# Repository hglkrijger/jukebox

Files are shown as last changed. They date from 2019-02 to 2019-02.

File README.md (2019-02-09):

# Arduino NFC Jukebox

Recently, my wife and I had the idea of printing a song card for our 16 month old daughter. What this means is there are pictures printed on some cardstock which she can point to, and one of us sings the songs represented by that picture. 

After a few days of continuous singing, I decided to build a jukebox for her instead. I wanted to enable simple song selection using NFC cards with feedback from an LED. I also wanted to introduce her to the concept of sequences, while allowing her some simple level of control using a button. Finally, I would also need a way to change volume and other control functions.

This is a quick walkthrough for anyone who might like to do the same.

## Components

| Part | Link | Cost |
| ---|---|---|
| NTAG 215 NFC cards | [Amazon](https://www.amazon.com/gp/product/B075CL71FK/ref=ppx_yo_dt_b_asin_title_o01__o00_s00?ie=UTF8&psc=1) | ~60c ea |
| NTAG 213 NFC tags | [Amazon](https://www.amazon.com/gp/product/B07K6H6K43/ref=ppx_yo_dt_b_asin_title_o05__o00_s03?ie=UTF8&psc=1) | ~40c ea |
| DFPlayer mini | [Amazon](https://www.amazon.com/gp/product/B01MQD5IIA/ref=ppx_yo_dt_b_asin_title_o03__o00_s00?ie=UTF8&psc=1) | ~$4 |
| Power supply | [Amazon](https://www.amazon.com/gp/product/B06Y1LF8T5/ref=ppx_yo_dt_b_asin_title_o03__o00_s00?ie=UTF8&psc=1) | ~$9 |
| Illuminated latching switch | [Adafruit](https://www.adafruit.com/product/1442) | ~$2 |
| 3W speakers | [Amazon](https://www.amazon.com/gp/product/B0738NLFTG/ref=ppx_yo_dt_b_asin_title_o08__o00_s02?ie=UTF8&psc=1) | ~$8 |
| PN532 NFC shield | [Adafruit](https://www.adafruit.com/product/789) | ~$40 |
| Arduino Uno R3 | [Amazon](https://www.amazon.com/Elegoo-EL-CB-001-ATmega328P-ATMEGA16U2-Arduino/dp/B01EWOE0UU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) | ~$12 |
| Sandisk microSDHC card | [Amazon](https://smile.amazon.com/gp/product/B073JWXGNT/ref=oh_aui_search_asin_title?ie=UTF8&psc=1) | ~8 |

You will also need:

- Assorted brass standoffs
- Solid core wire
- Electrical insulation tape
- 8x M2 3mm screws (for speaker mounts)
- 4x M2 3mm screws (for Arduino mounts)
- 3x M2.5 3mm screws (for enclosure)
- 3x 2.5mm hex nuts (for enclosure)
- Soldering iron and solder
- MP3 songs

Total cost: ~$100

## Case

I designed the outer case and trim using Tinkercad, and printed in two colors. You can find all those parts here:

- [Back case](case/01%20-%20grey%20-%20back.stl)
- [Front case](case/02%20-%20grey%20-%20front.stl)
- [Trim, grey](case/03%20-%20grey%20-%20decoration.stl)
- [Trim, red](case/04%20-%20red%20-%20decoration.stl)

## Control tags

I found these handy key fobs on Thingiverse, which I used to represent control tags:

- [volume Up](https://www.thingiverse.com/thing:2852132)
- [volume Down](https://www.thingiverse.com/thing:2852051)
- [Stop](https://www.thingiverse.com/thing:2852109)

Scaling to 50% was a good size for these prints. The NFC stickers were attached to these, for use as controls. 

## Music

I purchased songs through iTunes, then converted the m4a files to mp3 directly using the iTunes app. These were copied over to the SD card according to this structure:

```
\01
    \0001.mp3
    \0002.mp3
    ...
    \0010.mp3
    \0011.mp3
    ...
```

Note the root folder is a 2-digit number, and the files are all 4-digit zero-prefixed. This is a requirement for the DFPlayer Mini. The numbering also makes it simpler to map the individual cards to songs.

## Writing tags and cards

Once the headers are soldered to the NFC shield, you can use the [nfcWriter](https://github.com/hglkrijger/jukebox/blob/master/src/nfcWriter.ino) to write an integer to each card. This integer must map to the file number of the song you want to select with that card. In other words, write `4` to the card to play `01\0004.mp3`. 

I used control tags for volume up, volume down, and stop. For these I selected `97`, `98`, and `99` as control codes, which were written to NFC tag stickers, and I attached those to little key fobs which I printed. 

## Circuit

Note the illuminated pushbutton is described by the LED and pusbutton parts. Also only one speaker is shown, but simply connect two speakers in the same way.

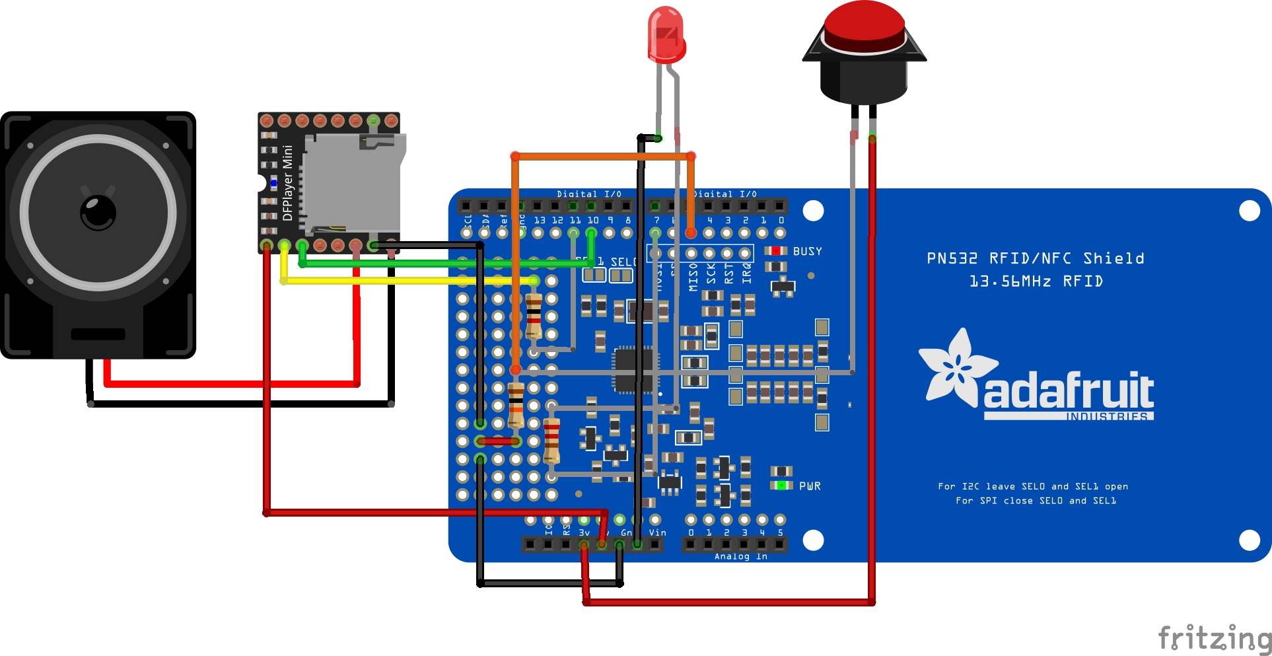
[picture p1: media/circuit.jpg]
Circuit Final circuit diagram


| Pin | Component |
|-----|---|
| 2 | pn532 irq |
| 3 | pn532 reset|
| 5 | button |
| 7 | led |
| 10 | dfplayer rx |
| 11 | dfplayer tx |
| 3V | button |
| 5V | dfplayer |
| GND | dfplayer, button, led |

## Assembly

1. Print all the case parts; glue trim to the front case
1. Print the key fobs, if you plan on using them
1. Solder the NFC shield headers
1. Solder solid core wires to the button; wrap with electrical insulation tape
1. Mount the button in the front case
1. Solder solid core wires to the DFPlayer; wrap with insulation tape
1. Solder the DFPlayer wires and resistors to the NFC shield as per the circuit diagram above
1. Mount the Arduino and speakers to the back case using standoffs
1. Mount the NFC shield on the Arduino board
1. Solder the button wires to the NFC shield as per the circuit diagram above
1. Place two small hex nuts in the case, which will catch the screws
1. Insert the SD card, connect power supply through the case, and screw the case closed
1. Decorate with stickers and mount :P

## Final result

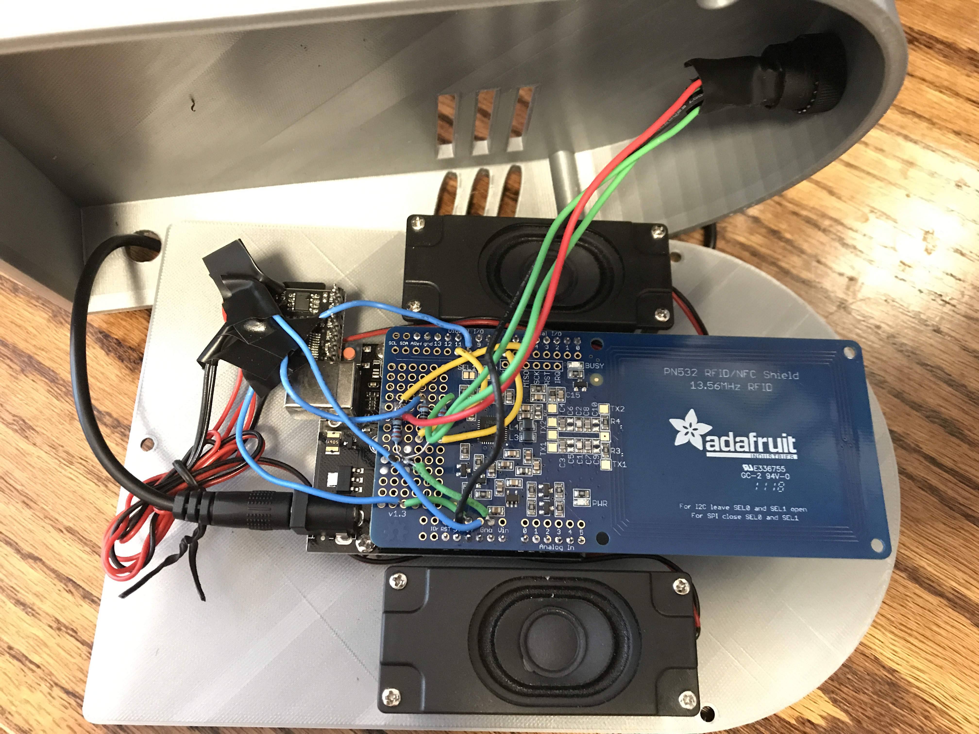
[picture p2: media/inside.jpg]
Inside Final mounted circuit inside


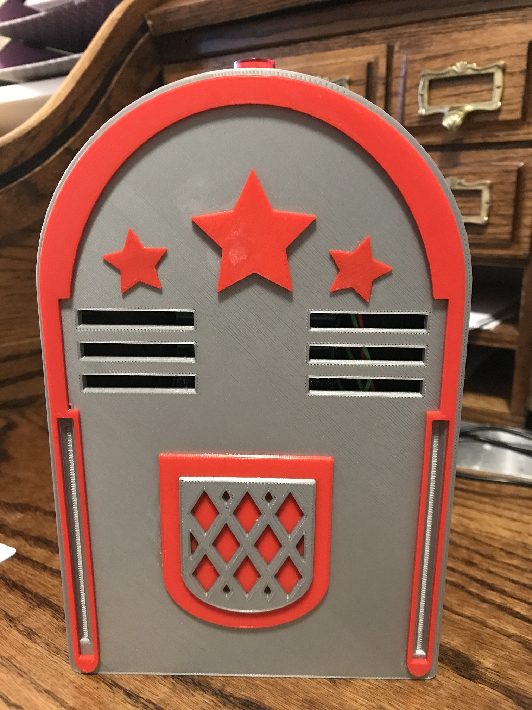
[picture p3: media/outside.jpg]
Outside Outside case


Action Action shot

## Notes

There are a few things I would change if I was doing this again:

1. Given the way the button is mounted to the front case, the soldering was a bit fiddly. I would either modify the case so that the button was mounted to the back case, or use alligator clips to attach the wires to the button connectors. 

1. The DFPlayer in my build was not mounted anywhere, and I did not make an opening to get access to the SD card. This means when I want to add more songs I need to open the case. Since I only have one NFC shield which doubles as a card writer and the jukebox reader, I had to open the case anyway. However, this could be improved.

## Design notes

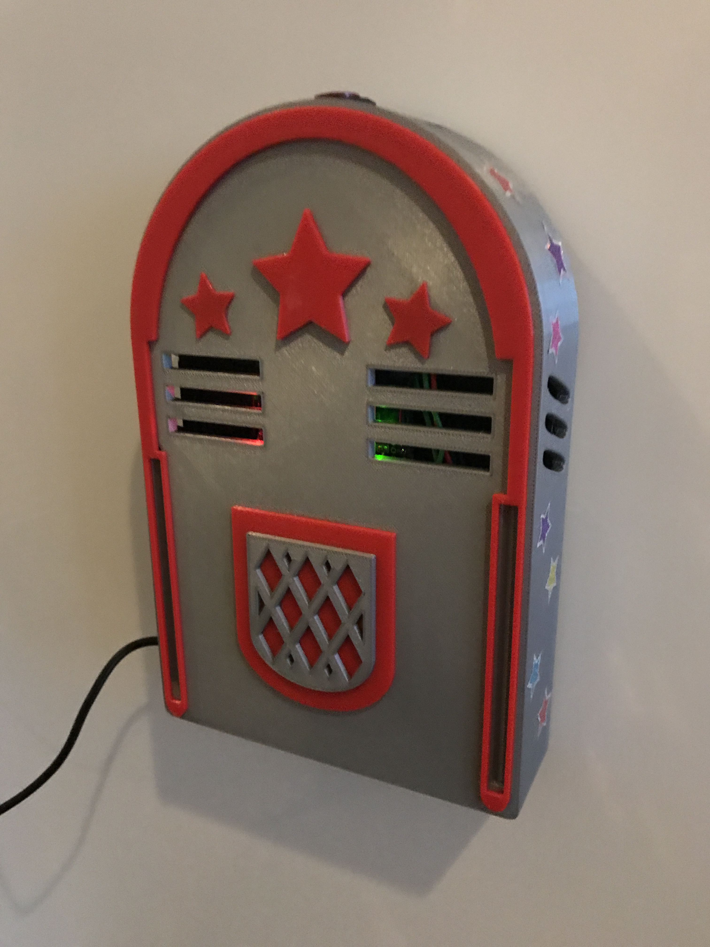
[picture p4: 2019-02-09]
media/mounted.jpg

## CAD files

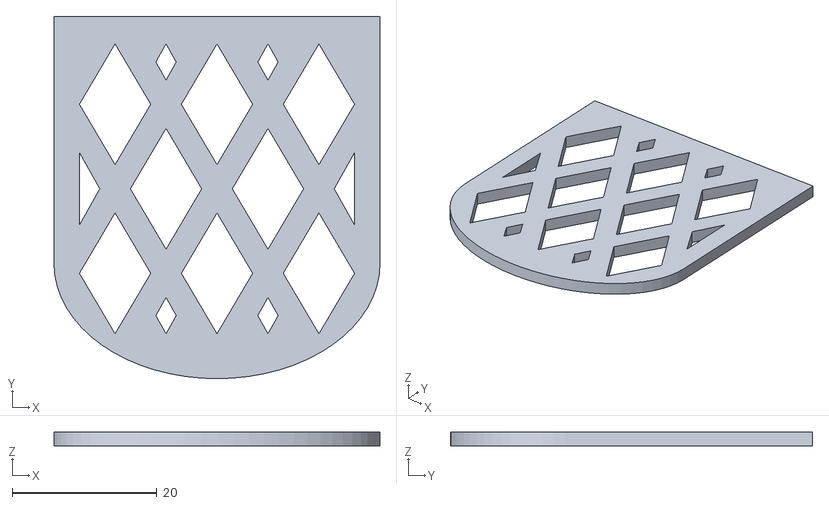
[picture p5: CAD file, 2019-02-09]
case/03 - grey - decoration.stl
45.0 x 50.0 x 2.00

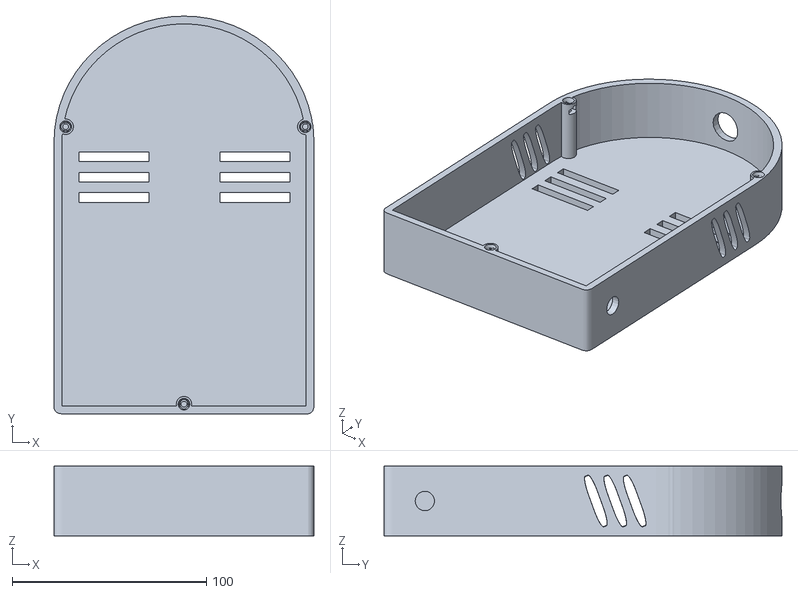
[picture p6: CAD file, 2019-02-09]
case/02 - grey - front.stl
134.0 x 205.0 x 36.0

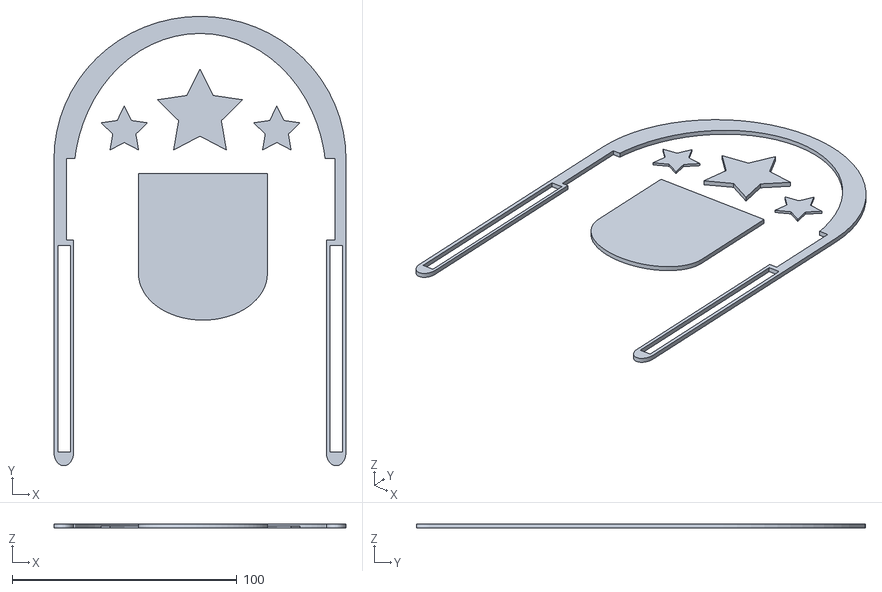
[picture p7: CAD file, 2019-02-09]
case/04 - red - decoration.stl
130.0 x 200.0 x 2.00

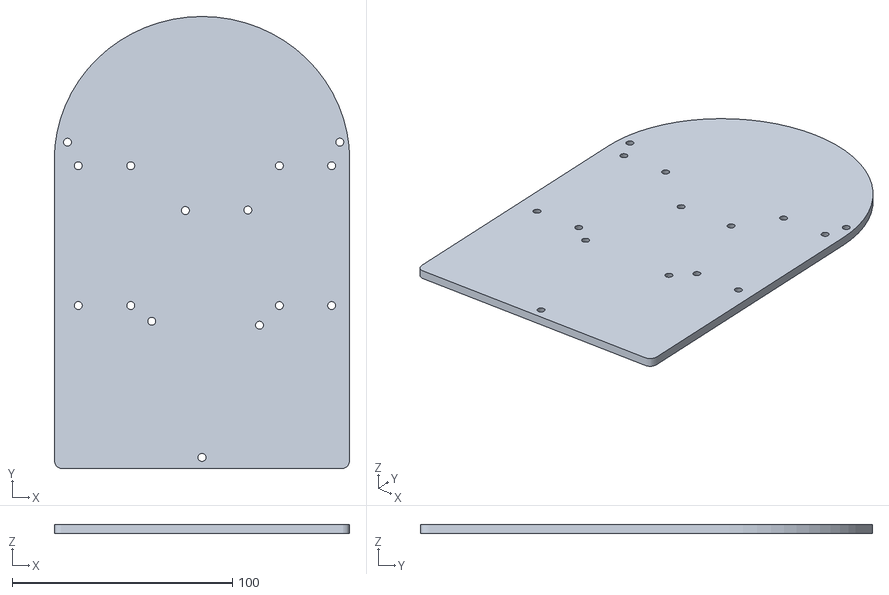
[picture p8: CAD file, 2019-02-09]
case/01 - grey - back.stl
134.0 x 205.0 x 4.00

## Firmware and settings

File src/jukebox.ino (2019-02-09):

#include <Adafruit_PN532.h>
#include <Arduino.h>
#include <DFRobotDFPlayerMini.h>
#include <SoftwareSerial.h>
#include <SPI.h>
#include <Wire.h>

#define PN532_IRQ   2
#define PN532_RESET 3
#define BUTTON      5
#define LED         7
#define DF_RX      10
#define DF_TX      11

#define VOL_UP     97
#define VOL_DN     98
#define STOP       99
 
int currentButtonState = 0;
int previousButtonState = 0;
int cardPage = 4;
int volume = 15;

bool stateChanged = false;
bool jukeboxOn = false;
bool isPlaying = false;

Adafruit_PN532 nfc(PN532_IRQ, PN532_RESET);
SoftwareSerial mySoftwareSerial(DF_RX, DF_TX);
DFRobotDFPlayerMini myDFPlayer;

/* button helpers */

void readButton()
{
  currentButtonState = digitalRead(BUTTON);

  if (previousButtonState != currentButtonState)
  {
    stateChanged = true;
    previousButtonState = currentButtonState;
  }
  else
  {
    stateChanged = false;
  }
}

bool isButtonPushed()
{
  return stateChanged && currentButtonState == HIGH;
}

bool isButtonReleased()
{
  return stateChanged && currentButtonState == LOW;
}

void lightOn()
{
  digitalWrite(LED, HIGH);
}

void lightOff()
{
  digitalWrite(LED, LOW);
}

void slowFlash()
{
  Serial.println("slow flash");
  flash(3, 500);
}

void fastFlash()
{
  Serial.println("fast flash");
  flash(6, 200);
}

void flash(int count, int speed)
{
  for (int i=0; i<count; i++)
  {
    lightOn();
    delay(speed);
    lightOff();
    delay(speed);
  }
}

void lightFlip()
{
  delay(350);
  digitalWrite(LED, !digitalRead(LED));
}

/* end button helpers */

/* nfc helpers */

void readTag()
{
  uint8_t success;
  uint8_t uid[] = { 0, 0, 0, 0, 0, 0, 0 };
  uint8_t uidLength;
    
  success = nfc.readPassiveTargetID(PN532_MIFARE_ISO14443A, uid, &uidLength);
  
  if (success) {
    if (uidLength == 7)
    {
      uint8_t data[32];
      success = nfc.ntag2xx_ReadPage(cardPage, data);

      if (success) 
      {
        Serial.print("tag id: ");
        int tagId = (int)data[0];
        Serial.println(tagId);

        if (tagId == STOP)
        {
          pause();
        } 
        else if (tagId == VOL_UP)
        {
          volume++;
          setVolume();
        } 
        else if (tagId == VOL_DN)
        {
          volume--;
          setVolume();
        } 
        else if (!isPlaying) {
          play(tagId);
        }
      }
      else
      {
        Serial.println("Unable to read the requested page!");
      }
    }
    else
    {
      Serial.println("This doesn't seem to be an NTAG203 tag (UUID length != 7 bytes)!");
    }
  }
}

/* end nfc helpers */

/* mp3 helpers */

void setVolume()
{
  volume = max(0, min(30, volume));

  Serial.print("volume: ");
  Serial.println(volume);
  myDFPlayer.volume(volume);
}

void play(int song)
{
  isPlaying = true;
  myDFPlayer.play(song);
  fastFlash();
}

void pause()
{
  isPlaying = false;
  myDFPlayer.pause();
  if (currentButtonState == HIGH)
  {
    lightOn();
  } else {
    lightOff();
  }
}

void checkPlayState()
{
  if (myDFPlayer.available()) {
    uint8_t type = myDFPlayer.readType();
    int value = myDFPlayer.read();
    
    switch (type) {
      case DFPlayerPlayFinished:
        pause();
        break;

      default:
        break;
    }
  }
}

/* end mp3 helpers */

void setup() {
  Serial.begin(9600);
  
  pinMode(LED, OUTPUT);
  pinMode(BUTTON, INPUT);
  slowFlash();

  Serial.println("setup nfc shield");
  nfc.begin();

  uint32_t versiondata = nfc.getFirmwareVersion();
  if (! versiondata) {
    Serial.print("Did not find PN53x board");
    while (1);
  }
  
  Serial.print("Found chip PN5"); Serial.println((versiondata>>24) & 0xFF, HEX); 
  Serial.print("Firmware ver. "); Serial.print((versiondata>>16) & 0xFF, DEC); 
  Serial.print('.'); Serial.println((versiondata>>8) & 0xFF, DEC);

  nfc.SAMConfig();
  nfc.setPassiveActivationRetries(0x01);

  Serial.println("setup dfplayer");
  mySoftwareSerial.begin(9600);
  while (!myDFPlayer.begin(mySoftwareSerial)) {
    Serial.println("dfplayer not ready");
    delay(5000);
    fastFlash();
  }
  int fileCount = myDFPlayer.readFileCounts();
  Serial.print("file count: ");
  Serial.println(fileCount);

  setVolume();
  Serial.println("dfplayer ready");
  
  Serial.println("ready");
}

void loop() {
  readButton();
  
  if (isButtonPushed())
  {
    Serial.println("button pushed");
    lightOn();
    jukeboxOn = true;
  }
  
  if (isButtonReleased())
  {
    Serial.println("button released");
    lightOff();
    jukeboxOn = false;
    pause();
  }

  if (jukeboxOn)
  {
    readTag();
    checkPlayState();
    if (isPlaying)
    {
      lightFlip();
    }
  }

  delay(500);
}

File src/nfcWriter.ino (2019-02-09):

#include <Wire.h>
#include <SPI.h>
#include <Adafruit_PN532.h>

#define PN532_IRQ   (2)
#define PN532_RESET (3)  // Not connected by default on the NFC Shield

int page=4;
uint8_t written=0;
String inString = "";
int cardData = 0;

Adafruit_PN532 nfc(PN532_IRQ, PN532_RESET);

void setup(void) {
  Serial.begin(9600);
  Serial.println("Initializing..");
  nfc.begin();

  uint32_t versiondata = nfc.getFirmwareVersion();
  if (! versiondata) {
    Serial.print("Did not find PN53x board");
    while (1);
  }
  
  Serial.print("Found chip PN5"); Serial.println((versiondata>>24) & 0xFF, HEX); 
  Serial.print("Firmware ver. "); Serial.print((versiondata>>16) & 0xFF, DEC); 
  Serial.print('.'); Serial.println((versiondata>>8) & 0xFF, DEC);

  nfc.SAMConfig();

  nfc.setPassiveActivationRetries(0x01);

  Serial.println("Enter a number to write...");
}

void readSerial()
{
  char c = ' ';
  while (Serial.available() > 0) {
    int inChar = Serial.read();
    if (isDigit(inChar)) {
      // convert the incoming byte to a char and add it to the string:
      inString += (char)inChar;
    }
    // if you get a newline, print the string, then the string's value:
    if (inChar == '\n') {
      int intValue = inString.toInt();
      if (intValue < 255 && intValue > 0) {
        cardData = intValue;
        written = 0;
      } else {
        Serial.println("Invalid value");
      }
      Serial.print("Value: ");
      Serial.println(cardData);
      // clear the string for new input:
      inString = "";
    }
  }
}

void writeTag()
{
  if (written) {
    return;
  }
  
  uint8_t success;
  uint8_t uid[] = { 0, 0, 0, 0, 0, 0, 0 };  // Buffer to store the returned UID
  uint8_t uidLength;                        // Length of the UID (4 or 7 bytes depending on ISO14443A card type)
    
  // Wait for an NTAG203 card.  When one is found 'uid' will be populated with
  // the UID, and uidLength will indicate the size of the UUID (normally 7)
  success = nfc.readPassiveTargetID(PN532_MIFARE_ISO14443A, uid, &uidLength);

  if (success) {
    if (uidLength == 7)
    {
      uint8_t data[32];
      Serial.print("Writing: ");
      Serial.println(cardData);
      
      memset(data, 0, 4);

      data[0] = cardData;
      
      success = nfc.ntag2xx_WritePage(page, data);
      
      // Display the results, depending on 'success'
      if (success) 
      {
        Serial.println("Success");
        written = 1;
      }
      else
      {
        Serial.println("Unable to write to the requested page!");
      }    
    }
    else
    {
      Serial.println("This doesn't seem to be an NTAG203 tag (UUID length != 7 bytes)!");
    }
  }
}

void readTag()
{
  uint8_t success;
  uint8_t uid[] = { 0, 0, 0, 0, 0, 0, 0 };  // Buffer to store the returned UID
  uint8_t uidLength;                        // Length of the UID (4 or 7 bytes depending on ISO14443A card type)
    
  // Wait for an NTAG203 card.  When one is found 'uid' will be populated with
  // the UID, and uidLength will indicate the size of the UUID (normally 7)
  success = nfc.readPassiveTargetID(PN532_MIFARE_ISO14443A, uid, &uidLength);
  
  if (success) {
    // Display some basic information about the card
    //Serial.println("Found an ISO14443A card");
    //Serial.print("  UID Length: ");Serial.print(uidLength, DEC);Serial.println(" bytes");
    //Serial.print("  UID Value: ");
    //nfc.PrintHex(uid, uidLength);
    //Serial.println("");
    
    if (uidLength == 7)
    {
      uint8_t data[32];
      
      // We probably have an NTAG2xx card (though it could be Ultralight as well)
      //Serial.println("Seems to be an NTAG2xx tag (7 byte UID)");    
      
      success = nfc.ntag2xx_ReadPage(page, data);
      
      // Display the current page number
      //Serial.print("PAGE ");
      //Serial.print(page);
      //Serial.print(":");

      // Display the results, depending on 'success'
      if (success) 
      {
        // Dump the page data
        //nfc.PrintHexChar(data, 4);

        Serial.print("Read value: ");
        Serial.println(data[0], DEC);
      }
      else
      {
        Serial.println("Unable to read the requested page!");
      }

      // Wait a bit before trying again
      Serial.println("\nEnter to write another tag");
      Serial.flush();
      while (!Serial.available());
      while (Serial.available()) { Serial.read(); }
      Serial.println("Ready");
    }
    else
    {
      Serial.println("This doesn't seem to be an NTAG203 tag (UUID length != 7 bytes)!");
    }
  }
}

void loop(void) 
{
  readSerial();
    
  writeTag();

  readTag();
  
  delay(500);
}

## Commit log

2019-02-09 adding case models
    adding case models
    [01 - grey - back.stl, 02 - grey - front.stl, 03 - grey - decoration.stl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]
2019-02-09 Update README.md
    updating the readme with parts and case
2019-02-09 adding circuit diagram
    [jukebox.fzz]
